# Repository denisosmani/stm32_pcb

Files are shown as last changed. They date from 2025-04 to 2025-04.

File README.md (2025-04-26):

# STM32 Custom Development Board

A custom-designed STM32F103C8T6 development board featuring essential components for easy programming, communication, and expansion.

## Features
- USB Micro-B port for power and communication
- AMS1117-3.3 voltage regulator
- BOOT0 switch for programming mode selection
- 16 MHz external crystal oscillator
- SWD 4-pin header for programming/debugging
- I2C and UART pin headers for peripheral connections
- Compact and robust PCB design

## Hardware Overview

### Schematic View
The schematic includes the STM32F103C8T6 microcontroller, voltage regulation, USB interface, programming headers, and peripheral connectors.

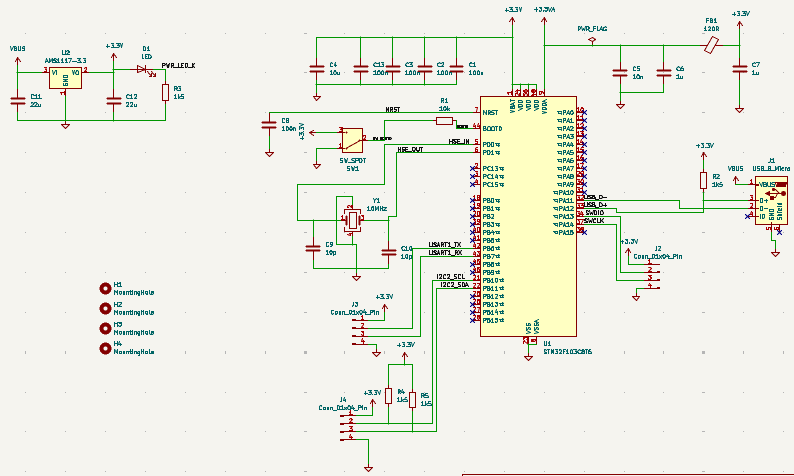
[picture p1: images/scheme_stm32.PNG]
Schematic


### PCB Layout and Routing
The PCB is routed to ensure stable operation, minimal noise, and good power distribution.

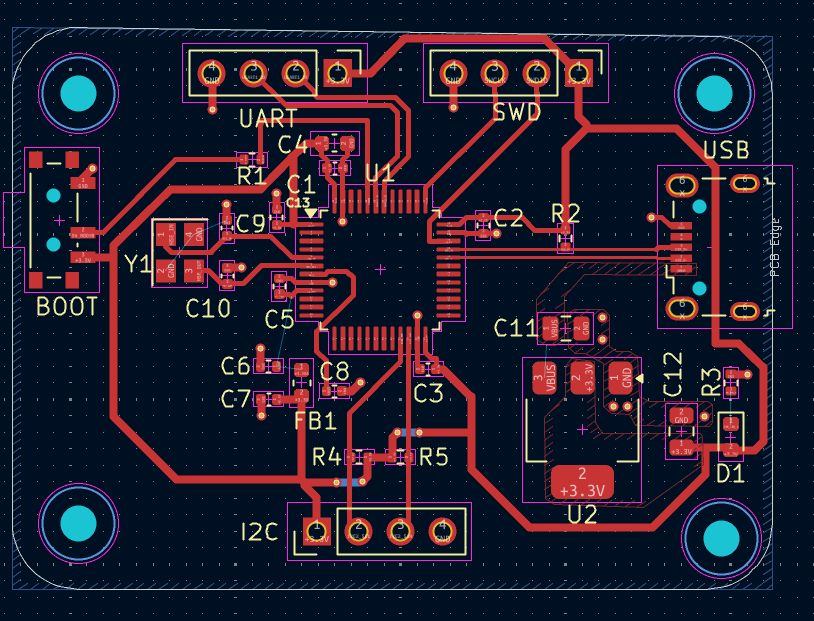
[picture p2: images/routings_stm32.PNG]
Routing and Layout


### 3D PCB View
A realistic 3D view of the assembled PCB.

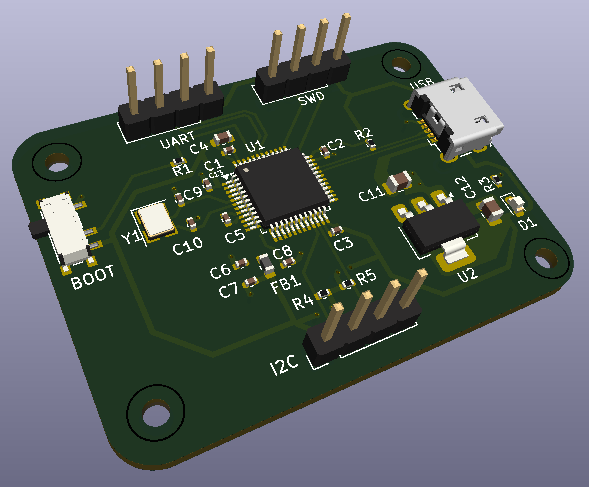
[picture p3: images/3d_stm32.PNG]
3D PCB View


## Components
- **Microcontroller:** STM32F103C8T6
- **Voltage Regulator:** AMS1117-3.3
- **Clock:** 16 MHz Crystal Oscillator
- **Communication:** USB Micro-B port, I2C header, UART header
- **Programming:** SWDIO 4-pin header, BOOT0 switch for mode selection

### Programming the Board
- Use an SWD programmer (such as ST-Link V2) connected to the SWDIO 4-pin header.
- Set the BOOT0 switch appropriately when flashing firmware:
  - **Programming mode:** BOOT0 = HIGH
  - **Normal operation:** BOOT0 = LOW

### Powering the Board
- Power can be provided through the USB Micro-B port or an external 5V supply.

### Pin Headers
- **I2C Header:** Connect external I2C peripherals.
- **UART Header:** Debug and communicate with other devices over UART.

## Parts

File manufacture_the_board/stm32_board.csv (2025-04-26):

Reference | Value | Footprint | Datasheet | Qty | DNP | Exclude from BOM | Exclude from Board
C1,C2,C3,C8,C13 | 100n | Capacitor_SMD:C_0402_1005Metric | ~ | 5
C4 | 10u | Capacitor_SMD:C_0603_1608Metric | ~ | 1
C5 | 10n | Capacitor_SMD:C_0402_1005Metric | ~ | 1
C6,C7 | 1u | Capacitor_SMD:C_0402_1005Metric | ~ | 2
C9,C10 | 10p | Capacitor_SMD:C_0402_1005Metric | ~ | 2
C11,C12 | 22u | Capacitor_SMD:C_0805_2012Metric | ~ | 2
D1 | LED | LED_SMD:LED_0603_1608Metric | ~ | 1
FB1 | 120R | Inductor_SMD:L_0603_1608Metric | ~ | 1
H1,H2,H3,H4 | MountingHole | MountingHole:MountingHole_2.2mm_M2 | ~ | 4 |  | Excluded from BOM
J1 | USB_B_Micro | Connector_USB:USB_Micro-B_Wuerth_629105150521 | ~ | 1
J2,J3,J4 | Conn_01x04_Pin | Connector_PinHeader_2.54mm:PinHeader_1x04_P2.54mm_Vertical | ~ | 3
R1 | 10k | Resistor_SMD:R_0402_1005Metric | ~ | 1
R2,R3,R4,R5 | 1k5 | Resistor_SMD:R_0402_1005Metric | ~ | 4
SW1 | SW_SPDT | Button_Switch_SMD:SW_SPDT_PCM12 | ~ | 1
U1 | STM32F103C8T6 | Package_QFP:LQFP-48_7x7mm_P0.5mm | https://www.st.com/resource/en/datasheet/stm32f103c8.pdf | 1
U2 | AMS1117-3.3 | Package_TO_SOT_SMD:SOT-223-3_TabPin2 | http://www.advanced-monolithic.com/pdf/ds1117.pdf | 1
Y1 | 16MHz | Crystal:Crystal_SMD_3225-4Pin_3.2x2.5mm | ~ | 1

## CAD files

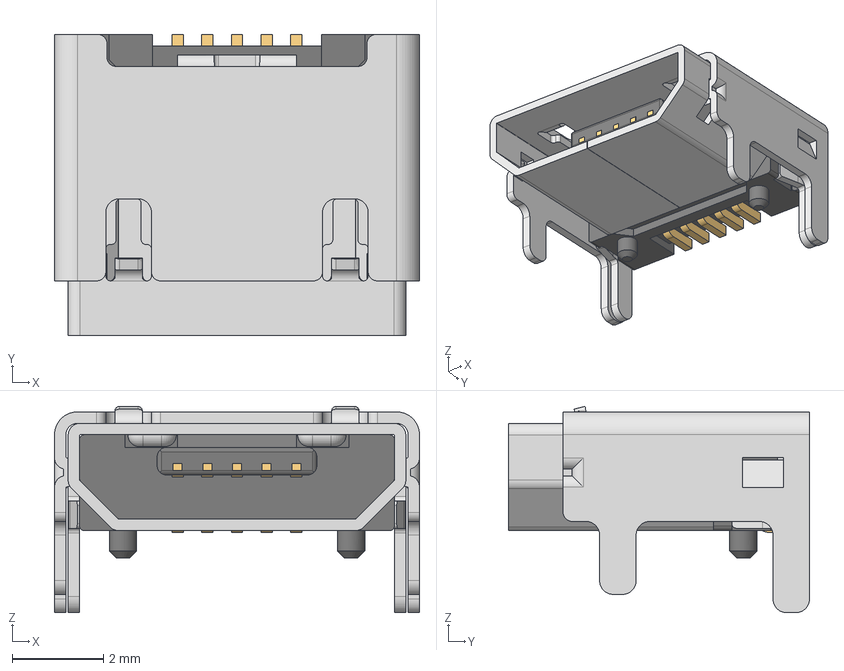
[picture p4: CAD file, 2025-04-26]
629105150521 (rev1).stp
8.00 x 6.60 x 4.52 mm
629105150521_Housing
629105150521_Pin1 x 4
629105150521_Pin2
629105150521_Shielding2
629105150521_Shielding

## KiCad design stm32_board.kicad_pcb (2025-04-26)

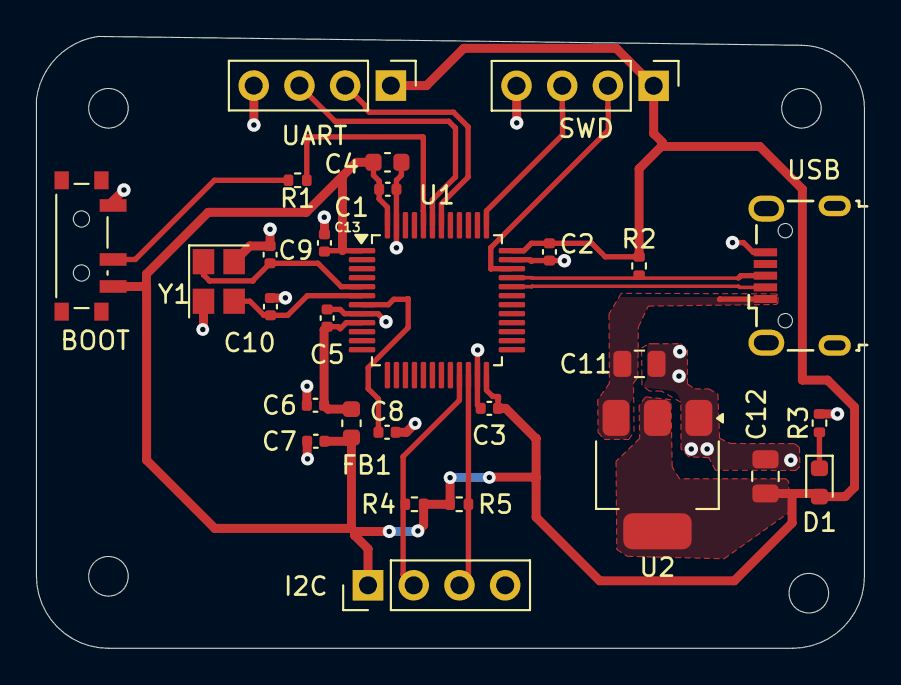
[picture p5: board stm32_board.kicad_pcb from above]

Board: 2 copper layers, 46.0 x 34.0 mm, 32 parts (0 on the bottom side), 18 nets.

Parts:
BOOT: SW_SPDT; SW_SPDT_PCM12
C1, C2, C3, C8, C13: 100n; C_0402_1005Metric
C4: 10u; C_0603_1608Metric
C5: 10n; C_0402_1005Metric
C6, C7: 1u; C_0402_1005Metric
C9, C10: 10p; C_0402_1005Metric
C11, C12: 22u; C_0805_2012Metric
D1: LED; LED_0603_1608Metric
FB1: 120R; L_0603_1608Metric
H1, H2, H3, H4: MountingHole; MountingHole_2.2mm_M2
I2C: Conn_01x04_Pin; PinHeader_1x04_P2.54mm_Vertical
R1: 10k; R_0402_1005Metric
R2, R3, R4, R5: 1k5; R_0402_1005Metric
SWD: Conn_01x04_Pin; PinHeader_1x04_P2.54mm_Vertical
U1: STM32F103C8T6; LQFP-48_7x7mm_P0.5mm
U2: AMS1117-3.3; SOT-223-3_TabPin2
UART: Conn_01x04_Pin; PinHeader_1x04_P2.54mm_Vertical
USB: USB_B_Micro; USB_Micro-B_Wuerth_629105150521
Y1: 16MHz; Crystal_SMD_3225-4Pin_3.2x2.5mm

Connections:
+3.3V: BOOT.3 (C), C1.1, C2.1, C3.1, C4.1, C7.1, C12.1, C13.1, D1.2 (A), FB1.2, I2C.1, R2.1, R4.1, R5.1, SWD.1, U1.1 (VBAT), U1.24 (VDD), U1.36 (VDD), U1.48 (VDD), U2.2 (VO), UART.1
+3.3VA: C5.1, C6.1, FB1.1, U1.9 (VDDA)
/BOOT0: R1.2, U1.44 (BOOT0)
/HSE_IN: C9.1, U1.5 (PD0), Y1.1
/HSE_OUT: C10.1, U1.6 (PD1), Y1.3
/I2C2_SCL: I2C.2, R4.2, U1.21 (PB10)
/I2C2_SDA: I2C.3, R5.2, U1.22 (PB11)
/NRST: C8.1, U1.7 (NRST)
/PWR_LED_K: D1.1 (K), R3.1
/SWCLK: SWD.3, U1.37 (PA14)
/SWDIO: SWD.2, U1.34 (PA13)
/SW_BOOT0: BOOT.2 (B), R1.1
/USART1_RX: U1.43 (PB7), UART.3
/USART1_TX: U1.42 (PB6), UART.2
/USB_D+: R2.2, U1.33 (PA12), USB.3 (D+)
/USB_D-: U1.32 (PA11), USB.2 (D-)
GND: BOOT.1 (A), C1.2, C2.2, C3.2, C4.2, C5.2, C6.2, C7.2, C8.2, C9.2, C10.2, C11.2, C12.2, C13.2, I2C.4, R3.2, SWD.4, U1.8 (VSSA), U1.23 (VSS), U1.35 (VSS), U1.47 (VSS), U2.1 (GND), UART.4, USB.5 (GND), Y1.2, Y1.4
VBUS: C11.1, U2.3 (VI), USB.1 (VBUS)
